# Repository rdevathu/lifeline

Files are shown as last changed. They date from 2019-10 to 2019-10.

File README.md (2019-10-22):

# Lifeline

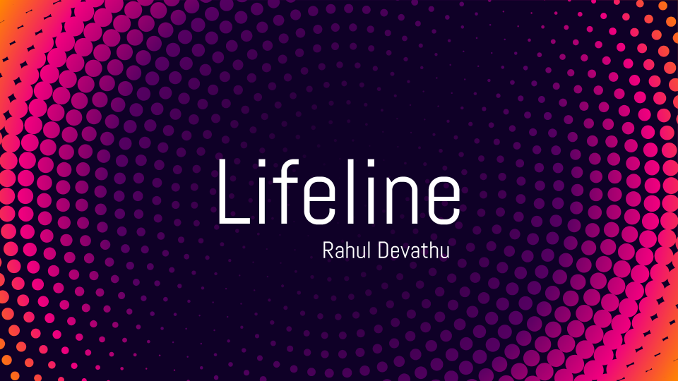
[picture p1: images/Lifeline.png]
Lifeline


Lifeline is a project that aims to create a low-cost high utility CPR vest that actively gives the user feedback and instruction on their compressions and additionally instruction on their rescue-breaths. Timing and efficency are critical when taking care of a patient undergoing a cardiac event. Every minute can increase their likelihood of survival incredibly. 

This project makes use of just a few major components which include:
- 3 Arduino Nanos
  - These microcontrollers split up the work among themselves to handle all the subfunctions that need to be dealt with.
- 1 HX711 Load Cell Amplifier  and 4 Load Cells
  - The HX711 reads the signal from the 4 loads cells to accurately tell the Arduino the load or force applied by the user.
- 1 SD Card Reader
  - This allows for the audio files to be stored and read.
- 1 Sound Amplifier
  - This allows the sound signal to be amplified before going out to the speakers and essentially drive the speakers.
- 2 Speakers
  - Allow for ample volume even in loud and hectic conditions so that the user is able to hear all commands clearly
- 1 Li-Ion Battery
  - Allows for wireless operation of the device and storage for longer periods. Also allows for greater portability
- Multiple non-function parts
  - All these parts are mounted on a vest which contains two load plates. The first load plate gives the user a comfortable place to rest and push with their hands and the second redistributes the load once it passes through the load cell. 
  
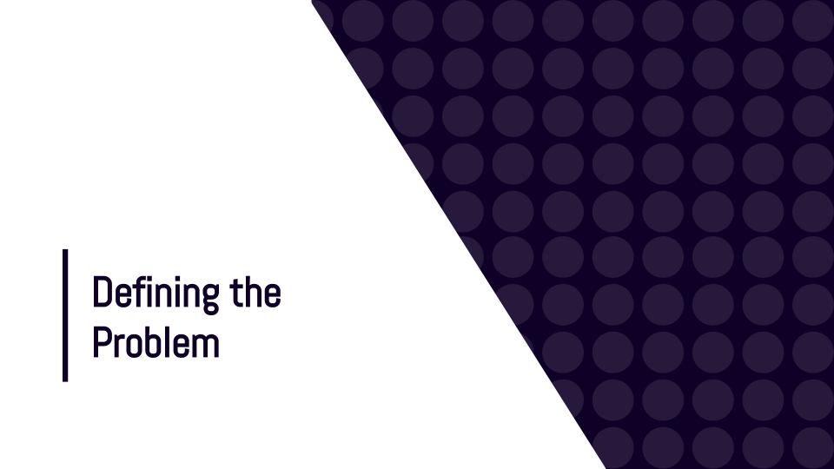
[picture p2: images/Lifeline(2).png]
Defining the Problem

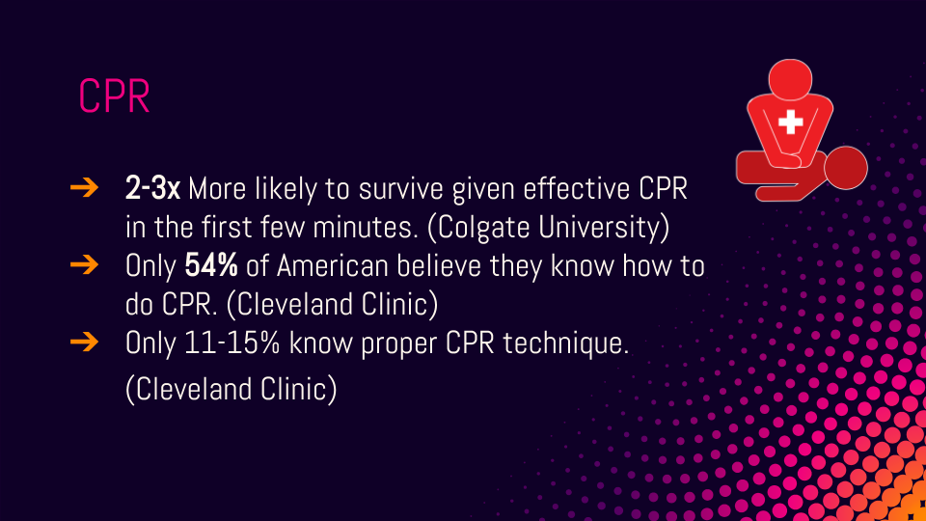
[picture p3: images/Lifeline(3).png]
CPR Stats

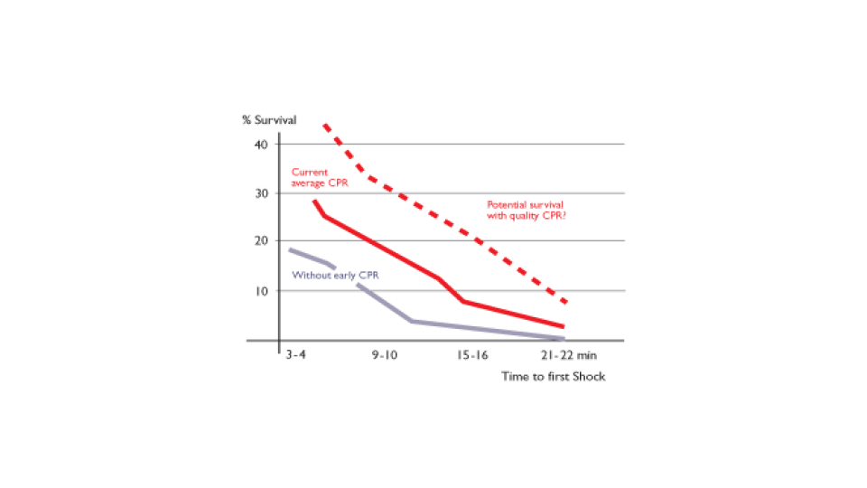
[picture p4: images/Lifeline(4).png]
Graph

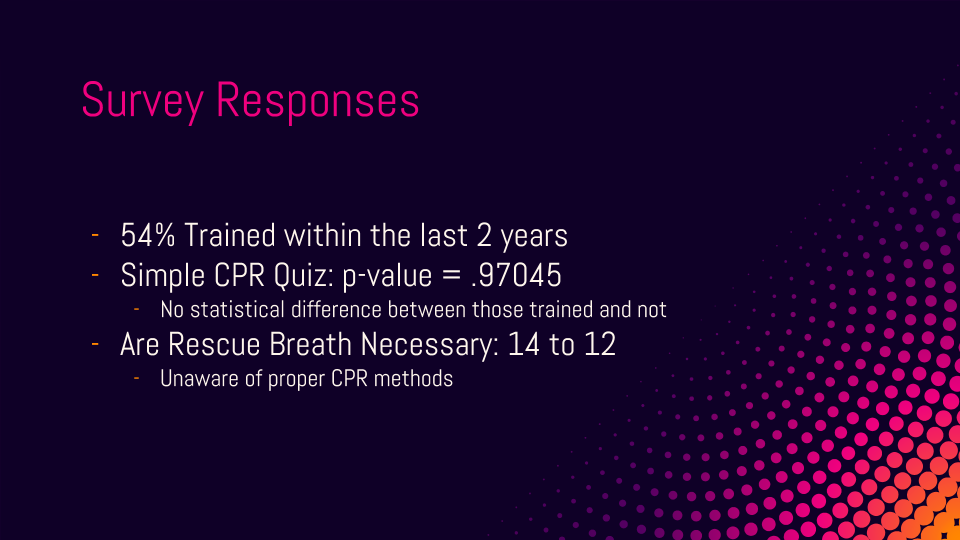
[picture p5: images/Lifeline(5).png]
Survey

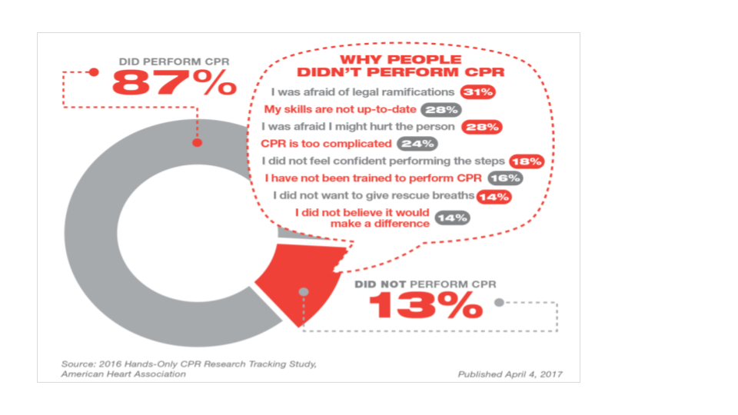
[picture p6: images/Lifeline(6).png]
Graphic

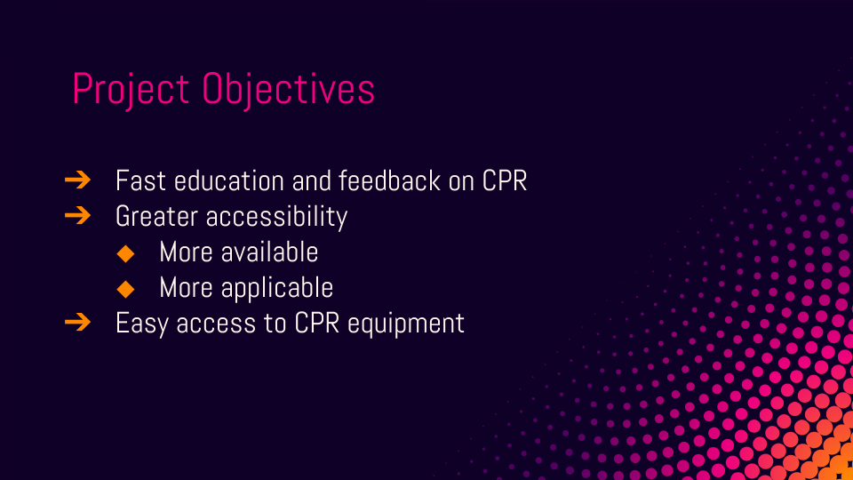
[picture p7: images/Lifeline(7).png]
Objectives

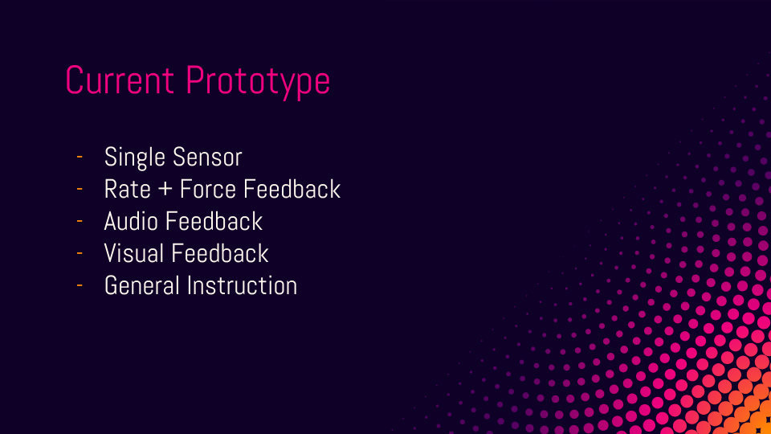
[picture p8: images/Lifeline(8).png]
CurrentPrototype

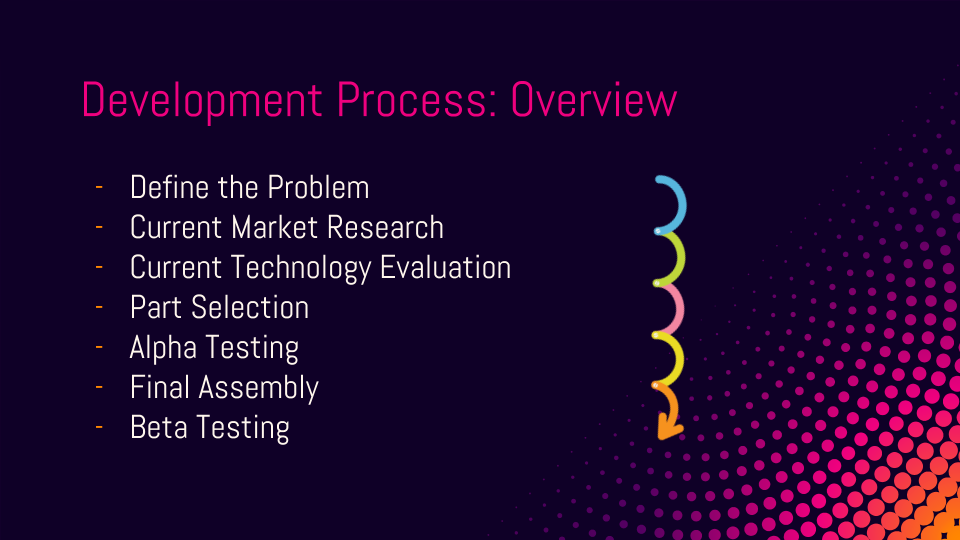
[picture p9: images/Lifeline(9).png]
DevProcess

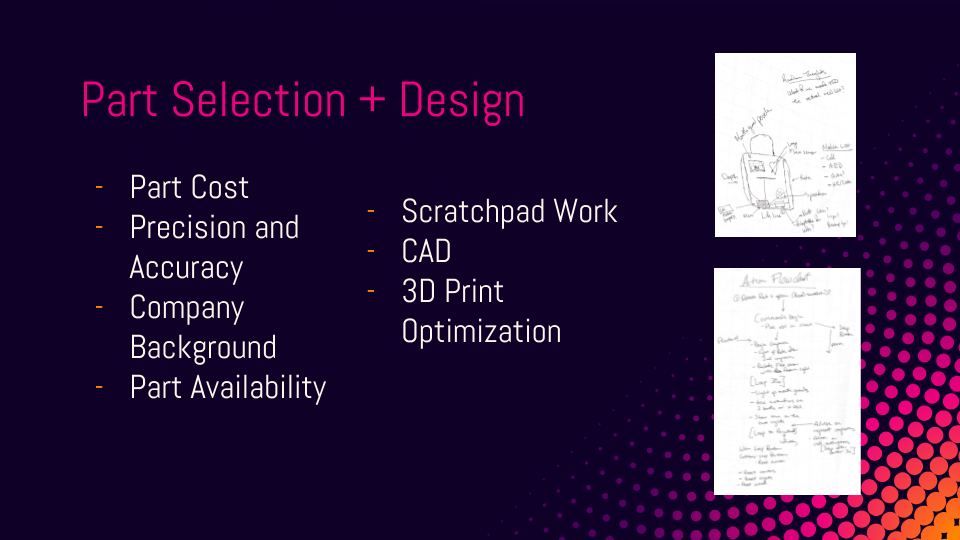
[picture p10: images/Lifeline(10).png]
Design

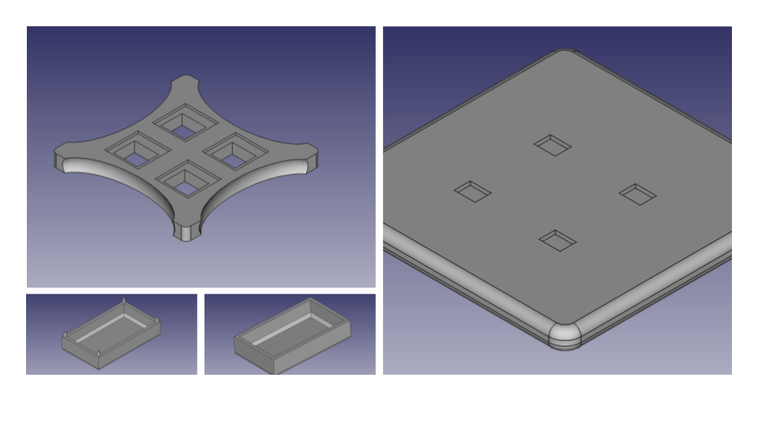
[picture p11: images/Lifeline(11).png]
STLs

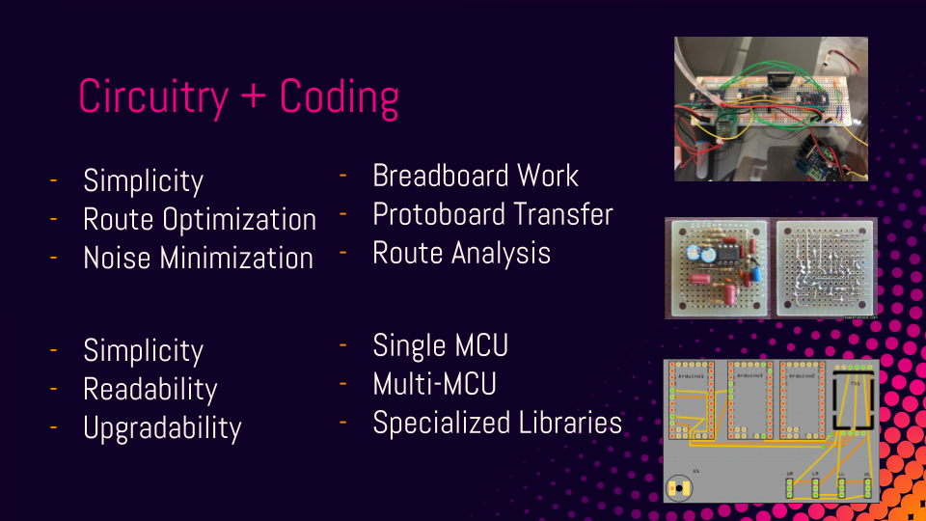
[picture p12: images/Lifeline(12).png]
Electronics

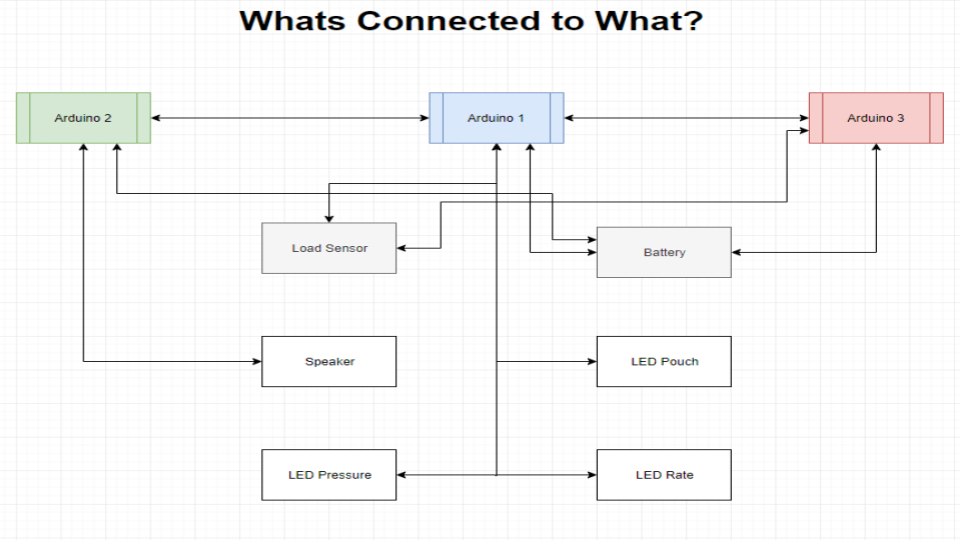
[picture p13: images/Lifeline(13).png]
Connections

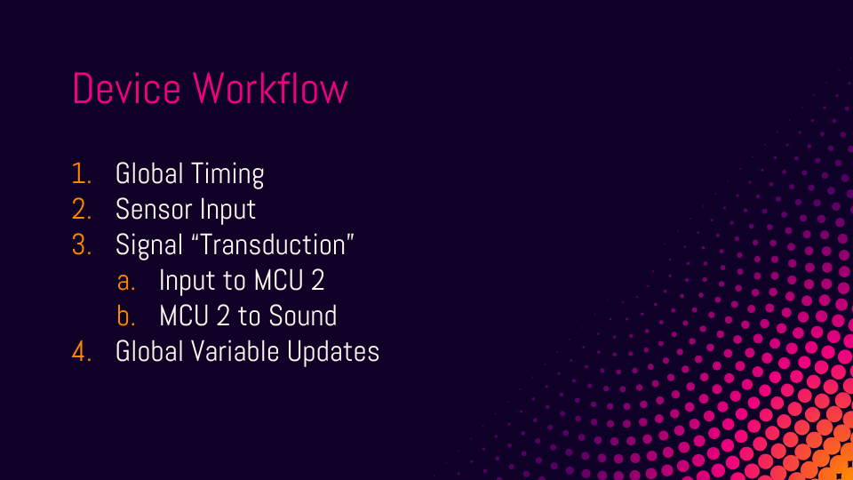
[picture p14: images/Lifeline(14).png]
Workflow

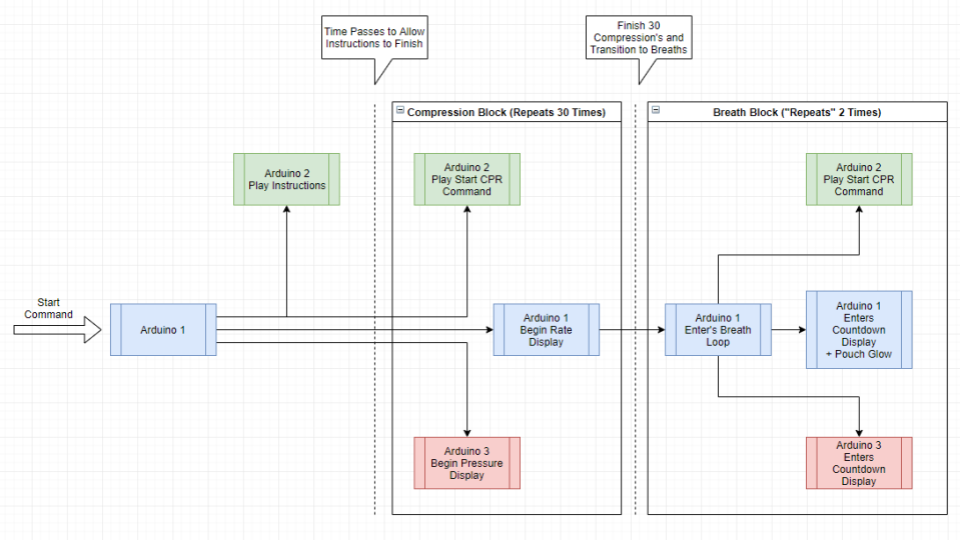
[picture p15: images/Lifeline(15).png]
WorkflowDiagram

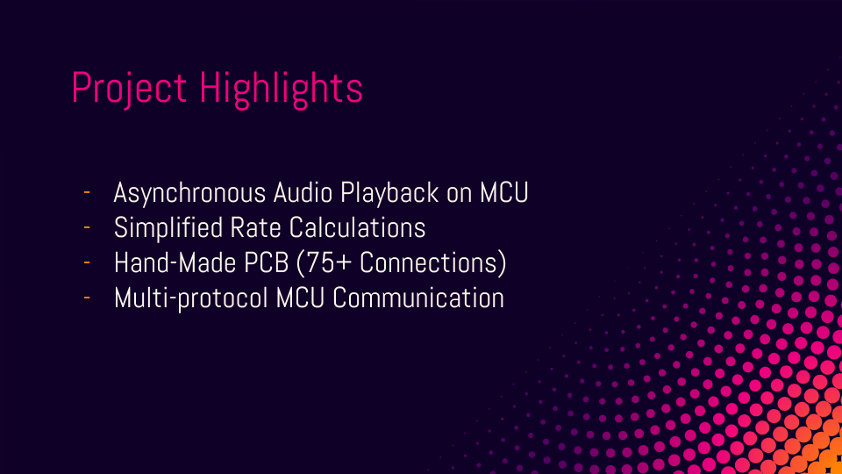
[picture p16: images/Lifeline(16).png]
Highlights

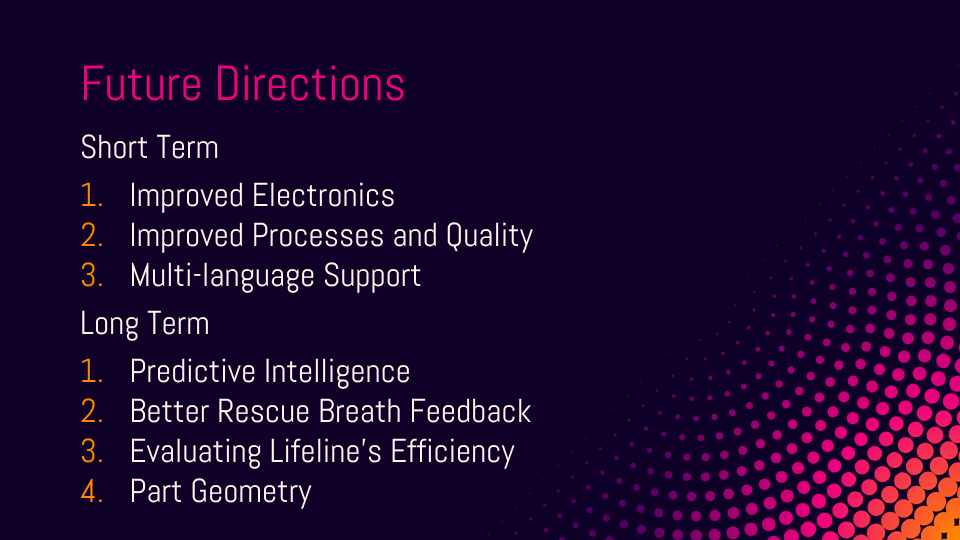
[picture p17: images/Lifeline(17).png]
Future

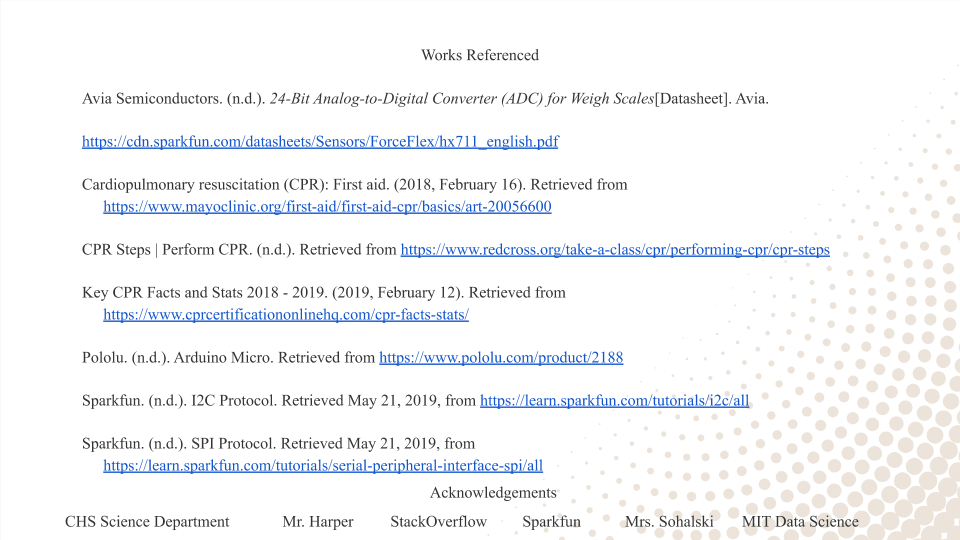
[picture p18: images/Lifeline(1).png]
Refs


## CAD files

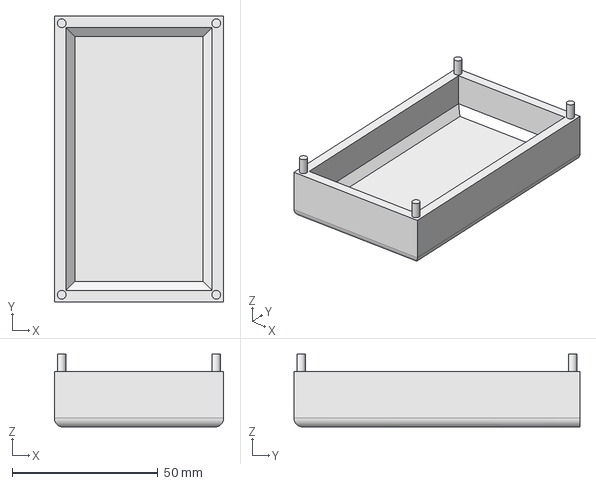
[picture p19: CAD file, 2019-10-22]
3DFiles/LifelineCase_Bottom.FCStd
58.0 x 98.0 x 25.0 mm

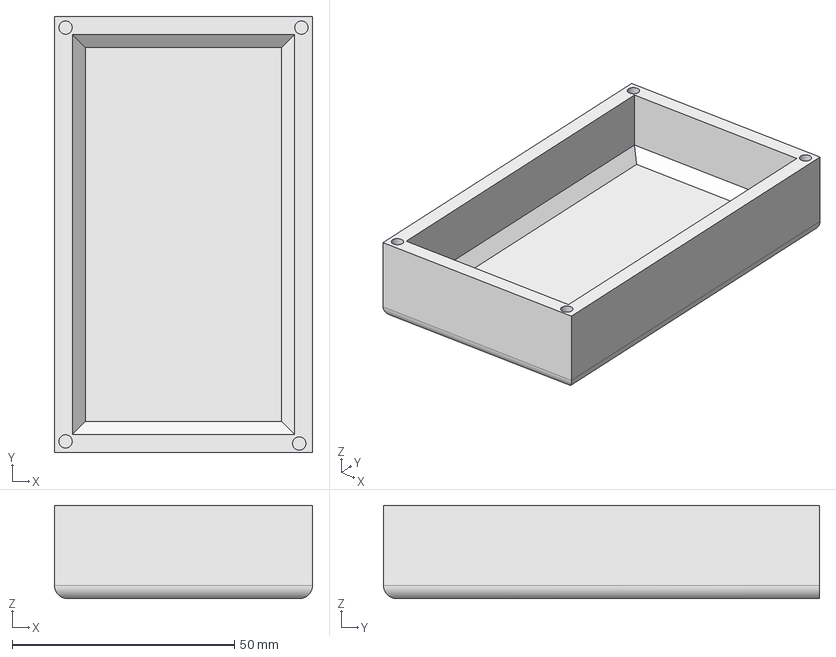
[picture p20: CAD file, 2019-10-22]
3DFiles/LifelineCase_Top.FCStd
58.0 x 98.0 x 21.0 mm

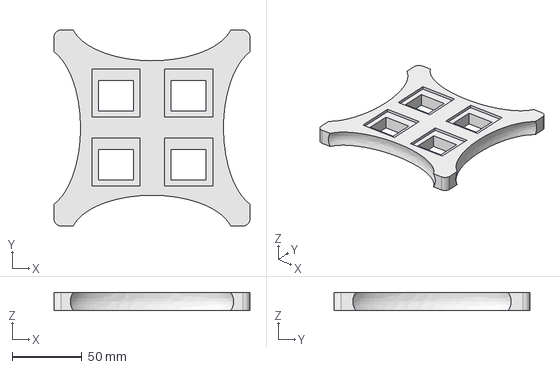
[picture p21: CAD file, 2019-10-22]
3DFiles/LifelineBody_Bottom.FCStd
140.0 x 140.0 x 13.0 mm

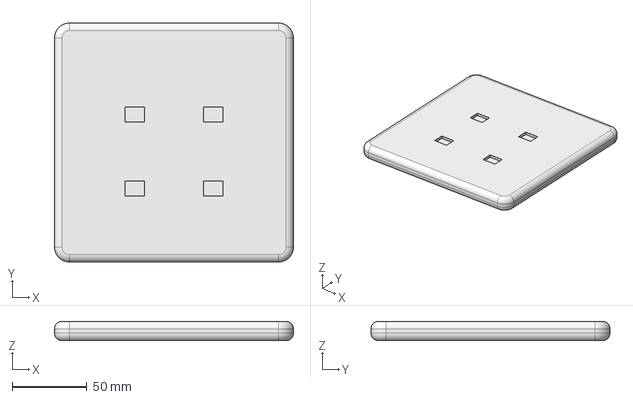
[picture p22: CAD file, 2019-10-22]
3DFiles/LifelineBody_Top.FCStd
160.0 x 160.0 x 13.0 mm

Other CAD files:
3DFiles/LifelineBody_Bottom.stl
3DFiles/LifelineBody_Top.stl
3DFiles/LifelineCase_Bottom.stl
3DFiles/LifelineCase_Top.stl

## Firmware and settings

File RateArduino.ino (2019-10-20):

//TODO: Update pin definitions
//300 LOC

//Inclusion of libraries that build up subfunctions or modules
#include <FastLED.h>
#include <Wire.h>
#include <EasyTransferI2C.h>


//Definitions for the LED Library
#define LED_PIN     4
#define NUM_LEDS    23
#define BRIGHTNESS  64
#define LED_TYPE    WS2811
#define COLOR_ORDER GRB
CRGB leds[NUM_LEDS];
#define UPDATES_PER_SECOND 100

//Definitions and global variables
const int switch_pin = 7; 
      //change this !!!

const int languageSwitch = 5;
char language = 'e';

int state = 0;
long time1 = 0;
long time2 = 0;
int flip = 0;
int sound = 8;

int waitCounter = 0;
int tempArr[100];
int gc = 0;

bool notPlayed = true;

//Setup for Microcontroller-microcontroller communication
EasyTransferI2C ET;
EasyTransferI2C ET2;

struct RECEIVE_DATA_STRUCTURE{
  //put your variable definitions here for the data you want to receive
  //THIS MUST BE EXACTLY THE SAME ON THE OTHER ARDUINO
  float readOut;
};

struct SEND_DATA_STRUCTURE{
  char message[6];
};

RECEIVE_DATA_STRUCTURE mydata;
SEND_DATA_STRUCTURE mydata2;



// Setup of microcontroller
void setup() {
  //LED Setup
  FastLED.addLeds<LED_TYPE, LED_PIN, COLOR_ORDER>(leds, NUM_LEDS).setCorrection( TypicalLEDStrip );
  FastLED.setBrightness( BRIGHTNESS );
  for(int led = 0; led< 23; led++){
    leds[led] = CRGB::Black;
  }
  FastLED.show();
  //Language Setup
  if(digitalRead(languageSwitch) == LOW){
    language = 's';
  }
  //MC-MC communications
  Wire.begin(9);        
  Serial.begin(9600); 
  ET.begin(details(mydata), &Wire);
  ET2.begin(details(mydata2), &Wire);
  Wire.onReceive(receive);
  //Sets up Pins
  pinMode(switch_pin, INPUT_PULLUP);
  pinMode(languageSwitch, INPUT_PULLUP);
  //pinMode(continue_button, INPUT_PULLUP);
  //Plays intro
  updateSound(-30);
        //delay time to play intro instructions
  delay(10000);

  Serial.println("Done Waiting");
}

// Function that allows for Rate LED to be updated.
void updateLED(){
  Serial.println("UPDATING");
  long looptime = time2-time1;
  Serial.println(looptime);
  float temp = 1/(float)looptime;
  int numLeds = (temp*8800);
  Serial.println("NUM LEDS = ");
  Serial.print(numLeds);
  for(int led = 0; led< 23; led++){
    leds[led] = CRGB::Black;
  }
  if(numLeds > 23){
    numLeds = 23;
  }
  for(int led = 0; led < numLeds; led++){
    leds[led] = CRGB::Red;
    if(led >=  8){
      leds[led] = CRGB::Orange;
    }
    if(led >= 12){
      leds[led] = CRGB::Green;
    }
    if(led >= 19){
      leds[led] = CRGB::Orange;
    }
    if(led >= 24){
      leds[led] = CRGB::Red;
    }
  }
 FastLED.show(); 
}

// Simple function that finds the largest number in an Array
int largest(int arr[], int n) { 
    int i; 
     
    // Initialize maximum element 
    int max = arr[0]; 
  
    // Traverse array elements from second and 
    // compare every element with current max   
    for (i = 1; i < n; i++) 
        if (arr[i] > max) 
            max = arr[i]; 
  
    return max; 
} 

// Function that allows transmission of various sound commands
void updateSound(int maxval){
  //Serial.println("??????");
  //Serial.println(maxval);
  //Serial.println("??????");
  if(maxval == -30){
    strcpy(mydata2.message, "s.wav");
    ET2.sendData(8);
    return;
  }
  if(maxval == -77){
    strcpy(mydata2.message, "b.wav");
    ET2.sendData(8);
    return;
  }
  if(maxval < 14){
     strcpy(mydata2.message, "l.wav");
     ET2.sendData(8);
  }
  if(maxval > 20){
    strcpy(mydata2.message, "h.wav");
    ET2.sendData(8);
  }
  

}


// Function that handles rescue breaths
void breathCount(){
  Serial.println("here");
   for(int led = 0; led< 8; led++){
    leds[led] = CRGB::Red;
  }
  for(int led = 7; led< 23; led++){
    leds[led] = CRGB::White;
  }
  for(int led = 23; led >0; led-=1){
    leds[led] = CRGB::Black;
    delay(45);
  }
  
}

// Major loop that controls the microcontroller
void loop() { 
 while(gc < 30){
 Serial.println(gc);
 if(ET.receiveData()){
   float val = mydata.readOut;
   switch(state){
     case 0:
      if(val >10){
        state = 1;
      }
      break;
     case 1:
      if(waitCounter < 100){
        //Serial.println("WC: ");
        //Serial.print(waitCounter);
        tempArr[waitCounter] = (int)val;
        waitCounter += 1;
      }
      if(waitCounter>100){
        memset(tempArr, 0, sizeof(tempArr));
      }
      //Serial.println("CASE 1");
      if(val < 10){
        state = 0;
        int n = sizeof(tempArr)/sizeof(tempArr[0]); 
        int maxval = largest(tempArr, n);
        int loop = 0;
        //Serial.println(" ");
        //for(loop = 0; loop < 100; loop++){
          //Serial.print(tempArr[loop]);
          //Serial.print(" ");
        //}
        
        updateSound(maxval);
        //gc += 1;
        memset(tempArr, 0, sizeof(tempArr));
        waitCounter = 0;
      if(flip == 0){
        time1 = millis();
        gc+=1;
        //Serial.println(time1);
        flip = 1;
      }else{
        time2 = millis();
        //Serial.println(time2);
        flip = 0;
        updateLED();
        gc+=1;
      }
      }
      break;
   }
  }
  delay(30);
  
 }

  //change this pin!!!
  const int pouchLed = 12;


 while(gc >= 30){
  if(notPlayed){
    updateSound(-77);
    notPlayed = false; }
    //digitalWrite to pouchLed pin
    analogWrite(pouchLed, 255);
    delay(100);
    analogWrite(pouchLed, 0);
    delay(100);
    analogWrite(pouchLed, 255);
    delay(100);
    analogWrite(pouchLed, 0);
    delay(100);
    analogWrite(pouchLed, 255);
    delay(100);
    analogWrite(pouchLed, 0);
    delay(100);
    analogWrite(pouchLed, 255);
    delay(100);
    analogWrite(pouchLed, 0);
    delay(100);
    analogWrite(pouchLed, 255);
    delay(100);
    analogWrite(pouchLed, 0);
    delay(100);
    //delay for the breath instructions
    delay(2000);
   //Serial.println("here-01");
   breathCount();
   gc+=1;
   if(gc == 32){
    gc = 0;
    notPlayed = true;
   }
 }
}


// Waste function that handles the interupt.
void receive(int numBytes) {}

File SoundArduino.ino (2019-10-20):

//Inclusion of libraries that build up subfunctions or modules
#include "SD.h"
#include "TMRpcm.h"
#include "SPI.h"
#include <Wire.h>
#include <EasyTransferI2C.h>

//Definitions, global variables, and creation of objects
#define SD_ChipSelectPin 10
TMRpcm tmrpcm;
EasyTransferI2C ET;

//Setup for Microcontroller-microcontroller communication
struct RECEIVE_DATA_STRUCTURE{
  //put your variable definitions here for the data you want to receive
  //THIS MUST BE EXACTLY THE SAME ON THE OTHER ARDUINO
  char message[6];
};
RECEIVE_DATA_STRUCTURE mydata;

// Setup of microcontroller
void setup(){
tmrpcm.speakerPin = 9;
pinMode(9, OUTPUT);
Serial.begin(9600);
Wire.begin(8);
ET.begin(details(mydata), &Wire);
Wire.onReceive(receiveEvent);

//Failure handling
if (!SD.begin(SD_ChipSelectPin)) {
  Serial.println("SD fail");
  return;
}

}

// Major loop that controls the microcontroller
void loop(){ 
  if(ET.receiveData()){
    Serial.println(mydata.message);
    tmrpcm.play(mydata.message);
  }

}

// Waste function that handles the interupt.
void receiveEvent(int howMany) {
}

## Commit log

2019-10-20 Create PressureArduino.ino
    This file contains the final code for the pressure Arduino. This Arduino is tasked with actually interfacing with the HX711 and then sending its read out to the other Arduinos as needed.
2019-10-20 Create RateArduino.ino
    This is the final code for the Rate Arduino. This Arduino is tasked with receiving the data from the Pressure Arduino and then calculating the rate of compressions and updating the rate LEDs it also 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
2019-10-20 Create SoundArduino.ino
    This is the final code for the Sound Arduino. This Arduino is tasked with communicating with the speaker module using the TMRpcm library (allows for asynchronous playback) and additionally receives i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
